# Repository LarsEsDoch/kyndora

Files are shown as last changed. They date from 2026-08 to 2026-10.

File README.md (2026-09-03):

# Kyndora

**Kyndora** is a connected device system that helps two people stay emotionally close across distance. A physical E-Ink display device sits with one partner ("at home"), while a companion mobile app lets the other partner ("away") share their mood, send messages, draw doodles, and let their return time count down, all visible on the device.

The project consists of a custom ESP32-S3 firmware, a FastAPI backend, an MQTT broker for real-time device communication, and a single Flutter app used by both partners.

---

## Table of Contents

- [Concept](#concept)
- [System Architecture](#system-architecture)
- [Hardware](#hardware)
- [Repository Structure](#repository-structure)
- [Features](#features)
  - [On the Device (E-Ink Display)](#on-the-device-e-ink-display)
  - [Mobile App](#mobile-app)
  - [Backend](#backend)
- [Tech Stack](#tech-stack)
- [Getting Started](#getting-started)
  - [Backend & Infrastructure](#backend--infrastructure)
  - [Firmware](#firmware)
  - [Mobile App](#mobile-app-1)
- [Device Provisioning Flow](#device-provisioning-flow)
- [CI/CD](#cicd)
- [Roadmap](#roadmap)
- [License](#license)

---

## Concept

Kyndora is built for couples, families, or friends who are temporarily apart. One person owns the **device**, a small E-Ink display box that sits on a desk or nightstand and passively shows information about their partner: current mood, a daily message, a hand-drawn doodle, the partner's local weather, and a countdown until they return.

The other person carries only the **app**. From anywhere, they can:

- Set their current mood and sleep status
- Send a message or draw a doodle for the day
- Set (or update) their return date/time
- Send an instant "Miss You" ping that lights up the LEDs on the partner's device
- Share their live location and timezone so the device always shows the correct weather and time

Both roles share the same app, the app simply adapts depending on whether a device is registered to the account or not.

## System Architecture

```
┌──────────────────┐        MQTT (WSS)        ┌───────────────────┐
│   ESP32-S3       │◄────────────────────────►│  Mosquitto Broker │
│   Kyndora Device │                          │  (mosquitto-go-   │
│  (E-Ink + LEDs)  │        HTTPS (REST)      │   auth backend)   │
└────────┬─────────┘◄─────────────────────────┴───────────┬───────┘
         │                                                │
         │                                        HTTP auth/ACL
         │                                                │
         ▼                                                ▼
┌─────────────────────────────────────────────────────────────────┐
│                        FastAPI Backend                          │
│  Auth (JWT) · Devices · Partners · Feed · Push · WebSocket      │
│  Weather worker · Timezone resolver · MQTT worker               │
└───────────┬────────────────────────────────────────┬────────────┘
            │                                        │
            ▼                                        ▼
     ┌─────────────┐                          ┌──────────────────┐
     │ PostgreSQL  │                          │  Flutter Mobile  │
     │  (SQLModel) │                          │  App (Android /  │
     └─────────────┘                          │  iOS PWA)        │
                                              └──────────────────┘
```

- The **device** communicates exclusively over MQTT for low-latency, device-only events (commands, status, telemetry) and falls back to plain HTTPS requests for content that doesn't fit an MQTT payload well (e.g. fetching the latest feed item).
- The **app** communicates with the backend over HTTPS for all actions and keeps a **WebSocket** connection open for real-time, user-facing events (partner requests, status changes, new feed items).
- **Push notifications** (Firebase Cloud Messaging for Android, Web Push/VAPID for the iOS PWA) ensure the app owner is notified even when the app isn't open.

## Hardware

| Component | Purpose |
|---|---|
| ESP32-S3 (DevKitC-1-N16R8) | Main microcontroller, WiFi + BLE |
| Waveshare 4.2" E-Paper Display | Primary display (GxEPD2, black/white, partial + full refresh) |
| SK6812 (WS2812B-compatible) LED strip | Ambient/indirect lighting, animations |
| BH1750 digital light sensor | Adaptive LED brightness based on ambient light |
| 4× physical buttons | Miss You, Power/Reset, Next, Previous |
| USB-C panel-mount connector | Power |

Pin mapping and full hardware notes live alongside the firmware source.

## Repository Structure

```
kyndora/
├── firmware/           # ESP32-S3 firmware (PlatformIO, C++/Arduino)
│   ├── include/         # Headers, fonts, icon assets
│   └── src/              # Managers: Display, MQTT, Light, Button, Update, Provisioning
├── backend/            # FastAPI backend (Python)
│   ├── routers/          # auth, device, partners, feed, mqtt, push, users, ws
│   ├── services/         # MQTT worker, weather worker, push, timezone
│   └── tests/            # pytest test suite
├── mobile_app/         # Flutter app (Android + iOS PWA)
│   └── lib/
│       ├── screens/      # Auth, provisioning, device detail, main layout
│       ├── tabs/          # Feed, Devices, Partner
│       └── services/     # Realtime (WebSocket), push, location
├── infrastructure/     # docker-compose, Mosquitto config
├── tools/              # Icon conversion pipeline (PNG → PROGMEM header)
└── .github/workflows/  # CI/CD for backend, firmware, and app
```

## Features

### On the Device (E-Ink Display)

The display is divided into fixed rows, each independently partial-refreshed to minimize flicker and E-Ink wear, with a full refresh every 20 partial updates and once per day:

- **Top bar**, freshness timestamp of the last message + WiFi signal / status icon
- **Time**, large, centered, NTP-synced and timezone-aware
- **Weather**, partner's current local weather icon + temperature (auto-selected icon based on weather code, day/night, and wind)
- **Daily message**, the partner's message for the day
- **Doodle**, the partner's hand-drawn daily doodle, rendered from an 80×80px 1-bit bitmap
- **Countdown**, live countdown until the partner's set return date/time
- **Location**, a short location label with a "stale" indicator if location data hasn't updated recently

Device-side logic includes:

- **LED lighting** with ambient-light-adaptive brightness (BH1750) and a "Miss You" sweep animation
- **Physical buttons** for sending an instant Miss You ping, plus day navigation
- **OTA firmware updates** over GitHub Releases, with support for a `stable` channel and a rolling `beta` channel
- **BLE provisioning** for zero-friction WiFi + account setup, entirely driven from the app
- **NVS-backed persistence** so return time, applied firmware version, timezone, and WiFi credentials survive reboots

### Mobile App

A single Flutter codebase serves both roles:

- **Feed tab**, view messages and doodles sent between partners
- **Devices tab**, list, add (via BLE provisioning), and configure owned devices; per-device settings for display elements, LED brightness/adaptive brightness/night mode, auto-update schedule, and device actions (restart, WiFi reset, cache clear, factory reset)
- **Partner tab**, add a partner by username, send/accept/decline partner requests, send messages, draw and send doodles, set return time, configure timezone (auto-detect via GPS or manual), log mood/sleep status, manage a rotating list of morning quotes, and send an instant "Miss You"
- **Real-time updates** via WebSocket with automatic exponential-backoff reconnection
- **Push notifications**, FCM on Android, Web Push (VAPID) on the installable iOS PWA
- **Background location updates** to keep the partner's weather and timezone accurate

### Backend

- **Auth**, Argon2 password hashing, JWT bearer tokens
- **Partner system**, request/accept/decline flow with real-time and push notifications
- **Device management**, provisioning tickets, per-device settings, telemetry, remote commands
- **MQTT integration**, a background worker consumes device status/heartbeat/telemetry/button events and updates the database; outbound commands are published to device-specific topics (`kyndora/<deviceId>/<topic>`)
- **Weather worker**, polls Open-Meteo every 15 minutes for each user's partner location and pushes updates to the device via MQTT
- **Timezone resolution**, automatic IANA timezone lookup from GPS coordinates, converted to POSIX TZ strings and pushed to the device
- **WebSocket hub**, per-user connection manager for real-time app events
- **Push service**, unified interface over Firebase Admin SDK (FCM) and `pywebpush` (Web Push)
- **Firmware proxy**, exposes a stable `/api/firmware/check` endpoint that resolves the latest GitHub Release asset per channel

## Tech Stack

**Firmware**
ESP32-S3 · PlatformIO · Arduino framework · GxEPD2 · ArduinoJson · PsychicMqttClient (WSS) · FastLED · BH1750 · Preferences (NVS) · BLE

**Backend**
Python · FastAPI · SQLModel · PostgreSQL · JWT (PyJWT) · Argon2 · Eclipse Mosquitto (mosquitto-go-auth, SSL) · firebase-admin · pywebpush · timezonefinder · Open-Meteo API

**Mobile**
Flutter/Dart · Firebase Cloud Messaging · Web Push/VAPID · flutter_blue_plus · geolocator · web_socket_channel

**Infrastructure**
Docker Compose · GitHub Actions (CI/CD) · GitHub Releases (OTA distribution) · GitHub Pages (iOS PWA hosting)

## Getting Started

### Backend & Infrastructure

```bash
cd infrastructure
docker compose up -d          # starts PostgreSQL and the Mosquitto broker
```

```bash
cd backend
python -m venv .venv && source .venv/bin/activate
pip install -r requirements.txt
cp .env.example .env          # configure DB_USER, DB_PASSWORD, JWT_SECRET, MQTT_PASSWORD, etc.
uvicorn main:app --reload
```

Run the test suite:

```bash
pytest
```

### Firmware

```bash
cd firmware
pio run                        # build
pio run -t upload              # flash to an ESP32-S3
```

The build expects an `FW_VERSION` environment variable (set automatically in CI); locally it falls back to `dev-local`.

### Mobile App

```bash
cd mobile_app
flutter pub get
flutter run                    # or: flutter build apk / flutter build web
```

## Device Provisioning Flow

1. The app requests a short-lived provisioning ticket from the backend (`POST /api/device/ticket`), scoped to the logged-in user.
2. The app connects to the device over BLE (advertised as `Kyndora-Setup`) and writes the WiFi SSID, WiFi password, and the provisioning ticket to dedicated GATT characteristics.
3. The device connects to WiFi and calls `POST /api/device/register` with its MAC address and the ticket.
4. The backend validates the ticket, creates (or reassigns) the device record, and returns a permanent device JWT plus MQTT credentials.
5. The device persists these credentials in NVS flash and connects to the MQTT broker over WSS from then on.

## CI/CD

Each part of the monorepo has its own GitHub Actions workflow, triggered on changes to its respective path:

- **`backend.yml`**, lint (ruff), test (pytest), build & push a Docker image to GHCR
- **`firmware.yml`**, build via PlatformIO, publish binaries to a rolling `beta` GitHub Release and to tagged releases
- **`app.yml`**, analyze, test, build Android APK and Flutter Web, deploy the iOS PWA to GitHub Pages, and publish artifacts to GitHub Releases

## Roadmap

- [ ] Tamagotchi-style mood/sleep visualization on the device display
- [ ] Certificate-pinned OTA downloads (replacing `setInsecure()`)
- [ ] LED behavior polish (night mode transitions, do-not-disturb mode)
- [ ] Device-side history browsing (past doodles, moods, locations)
- [ ] Special-event theming for the display

## License

This project is licensed under the GNU General Public License v3.0 - see the [LICENSE](LICENSE) file for details.

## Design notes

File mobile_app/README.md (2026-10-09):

# Kyndora

The official Kyndora App

## Getting Started

This project is a starting point for a Flutter application.

A few resources to get you started if this is your first Flutter project:

- [Learn Flutter](https://docs.flutter.dev/get-started/learn-flutter)
- [Write your first Flutter app](https://docs.flutter.dev/get-started/codelab)
- [Flutter learning resources](https://docs.flutter.dev/reference/learning-resources)

For help getting started with Flutter development, view the
[online documentation](https://docs.flutter.dev/), which offers tutorials,
samples, guidance on mobile development, and a full API reference.

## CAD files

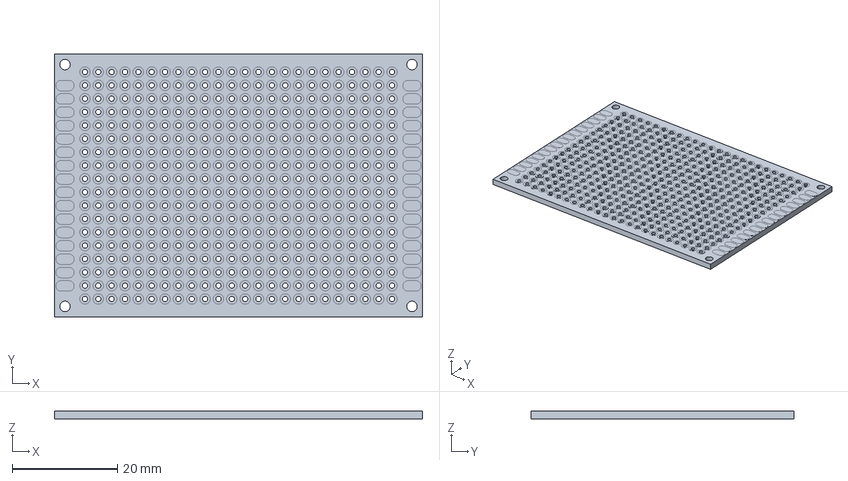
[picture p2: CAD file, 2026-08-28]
docs/cad/models/Perfboard 7x5.stp
70.0 x 50.0 x 1.55 mm

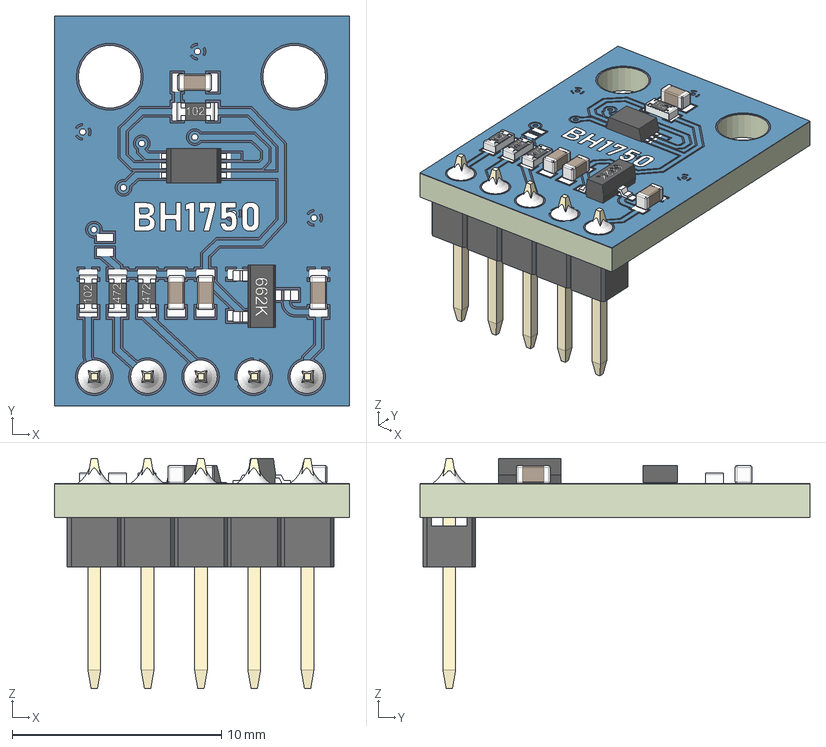
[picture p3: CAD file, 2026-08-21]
docs/cad/models/BH1750.step
14.1 x 18.6 x 11.0 mm
PCB
Font
Stift
Klammer
Solderpoints
662K
Capacitor
Resistor
Resistor (1) x 2
Capacitor (1)
Light-LED

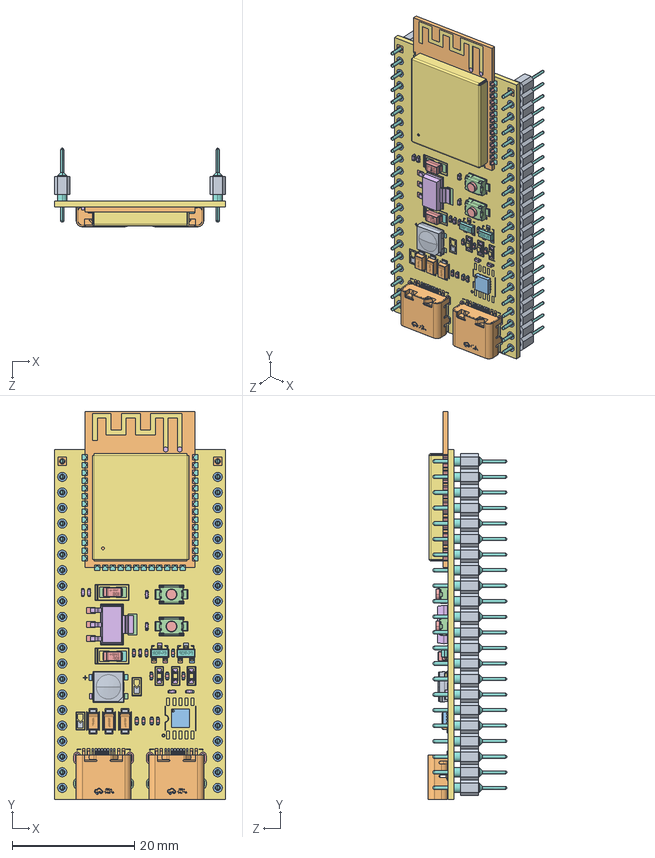
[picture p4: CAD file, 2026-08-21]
docs/cad/models/ESP32-S3-WROOM-1.STEP
27.9 x 63.4 x 12.9 mm
ESP32-S3-WROOM-1
Штыревой разъем 22 конт шаг 2.54мм x 2
USB-C_SMD-TYPE-C-31-M-12~USB-C_SMD-TYPE-C-31-M-12~QTmk.step.STEP x 2
2025-08-30-17-43-03-310.step.STEP x 2
WS2812B
SOT-223
SOT23-3 x 2
SOD-123F x 3
QFN-16 (3x3) Part1.stp
QFN-16 (3x3) Part2.stp x 16
ctantal_case-a_l3-2_w1-6_h1-6 x 2
Body.step x 3
Cover.step x 3
Cover_Mini.step x 3
Insides.step x 3
RC0402 x 10
0402_CA_CB_CC_CD x 7

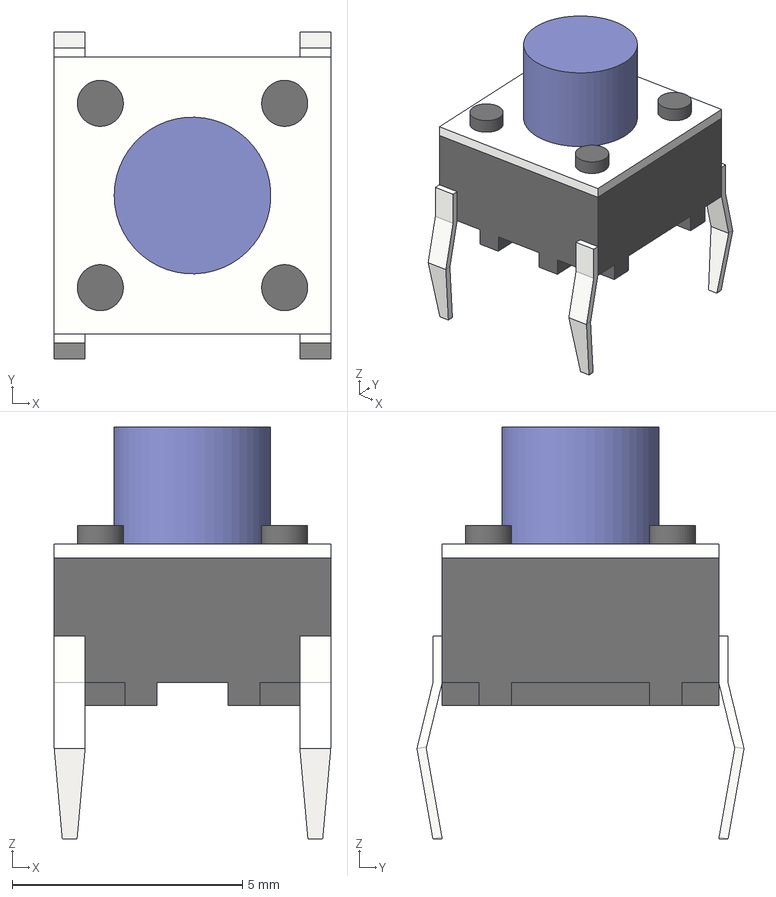
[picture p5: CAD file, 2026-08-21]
docs/cad/models/Micro Momentary Tactile Tact Touch Push Button Switch, 6x6x6 mm.step
6.00 x 7.10 x 8.94 mm

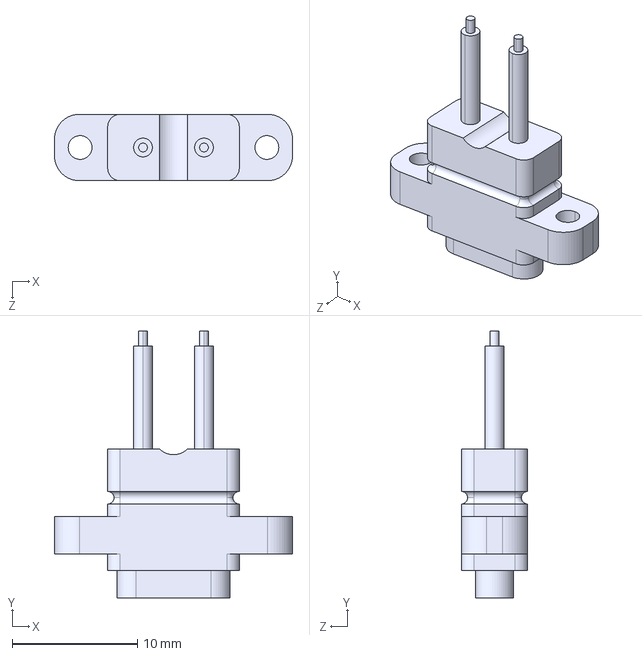
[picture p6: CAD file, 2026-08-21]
docs/cad/models/usb-c.STEP
19.0 x 21.3 x 5.30 mm

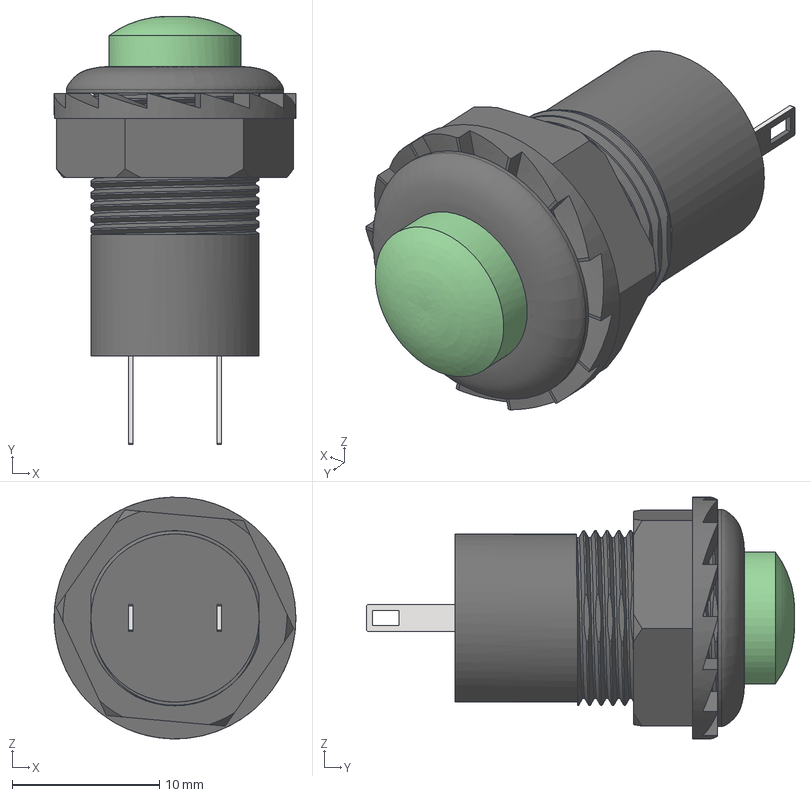
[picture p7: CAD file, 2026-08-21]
docs/cad/models/Momentary Push Button.step
16.4 x 29.0 x 16.4 mm

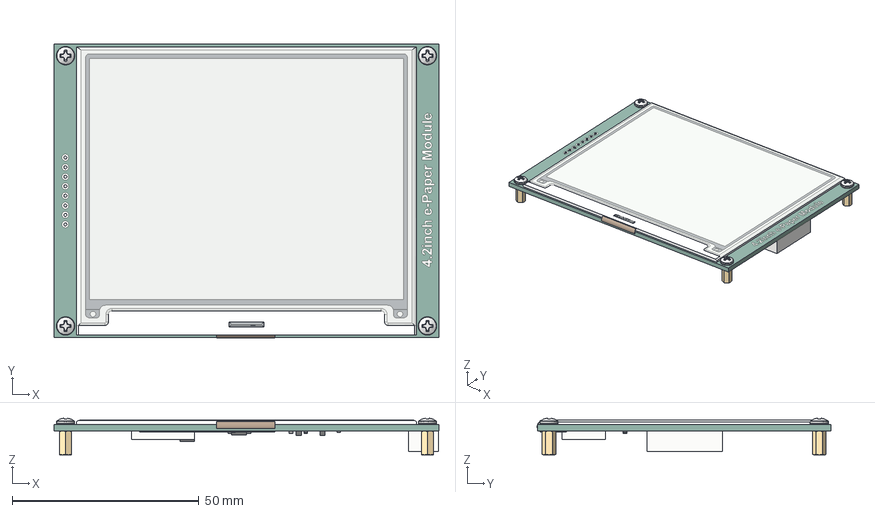
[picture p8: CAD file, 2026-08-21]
docs/cad/models/Waveshare 4.2inch e-Paper Module.step
103.0 x 78.6 x 9.79 mm
Waveshare 4.2 E-Ink - Display folded cable
PCB
90268A201 x 4
91772A030 x 4

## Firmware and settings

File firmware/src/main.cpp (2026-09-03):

#include <Arduino.h>
#include <SPI.h>
#include <WiFi.h>
#include <ctime>
#include "update.hpp"
#include "provisioning.hpp"
#include "mqtt_manager.h"
#include "light_manager.hpp"
#include "display_manager.h"
#include <ArduinoJson.h>
#include "button_manager.h"

#define PIN_EPD_CS    10
#define PIN_EPD_DC     9
#define PIN_EPD_RST   13
#define PIN_EPD_BUSY  46
#define PIN_EPD_SCK   12
#define PIN_EPD_MOSI  11

#define PIN_BTN_MISS_YOU 6
#define PIN_BTN_POWER    7
#define PIN_BTN_NEXT     5
#define PIN_BTN_PREV     4

auto ntpServer = "pool.ntp.org";
String timeZone  = "CET-1CEST,M3.5.0,M10.5.0/3";

uint32_t lastTimeMinutes = 0;
constexpr uint32_t intervalMinute = 60000;

const String otaChannel = "beta";

#ifndef FW_VERSION_STR
#define FW_VERSION_STR ""
#endif
const String currentVersion = String(FW_VERSION_STR).length() > 0 ? String(FW_VERSION_STR) : "dev-local";

DisplayManager displayManager(PIN_EPD_CS, PIN_EPD_DC, PIN_EPD_RST, PIN_EPD_BUSY);
UpdateManager updater(currentVersion, otaChannel, 3, displayManager);
LightManager lightManager;
MqttManager mqttManager;
ButtonManager buttonManager;

int lastMinute = -1;
int lastFullRefreshDay = -1;

uint32_t lastWifiCheck = 0;
constexpr uint32_t wifiCheckInterval = 5000;

bool ntpConfigured = false;
bool ntpSynced = false;
bool mqttStarted = false;
String savedMqttUser = "";
String savedMqttPass = "";
time_t savedReturnTime = 0;

uint32_t wifiDisconnectedSince = 0;
uint32_t lastWifiReconnectAttempt = 0;
constexpr uint32_t wifiReconnectInterval = 10000;
constexpr uint32_t WIFI_RESTART_TIMEOUT_MS = 10UL * 60UL * 1000UL;

constexpr uint32_t POWER_RESET_HOLD_MS = 5000;
bool powerHeld = false;
uint32_t powerHoldStart = 0;

bool getApiErrorFlag() {
    return mqttManager.hasApiError() || updater.hasUpdateError();
}

WifiIconState getCurrentWifiIconState() {
    if (!ProvisioningManager::isProvisioned()) return WIFI_ICON_NOT_SETUP;
    if (!ProvisioningManager::isWiFiConnected()) return WIFI_ICON_NOT_CONNECTED;
    if (getApiErrorFlag()) return WIFI_ICON_ALERT;

    int32_t rssi = WiFi.RSSI();
    if (rssi >= -60) return WIFI_ICON_STRENGTH_4;
    if (rssi >= -70) return WIFI_ICON_STRENGTH_3;
    if (rssi >= -80) return WIFI_ICON_STRENGTH_2;
    return WIFI_ICON_STRENGTH_1;
}

void handlePowerButtonReset() {
    bool pressed = digitalRead(PIN_BTN_POWER) == LOW;

    if (pressed) {
        if (!powerHeld) {
            powerHeld = true;
            powerHoldStart = millis();
        } else if (millis() - powerHoldStart >= POWER_RESET_HOLD_MS) {
            Serial.println("Power button 5s gehalten: Reset wird ausgeloest.");
            ProvisioningManager::reset();
        }
    } else {
        powerHeld = false;
    }
}

void setup() {
    Serial.begin(115200);

    updater.begin();

    SPI.begin(PIN_EPD_SCK, -1, PIN_EPD_MOSI, PIN_EPD_CS);
    displayManager.begin();
    lightManager.begin();
    buttonManager.begin(PIN_BTN_MISS_YOU, PIN_BTN_POWER, PIN_BTN_NEXT, PIN_BTN_PREV);

    ProvisioningManager::begin();

    if (ProvisioningManager::isProvisioned()) {
        Preferences preferences;
        preferences.begin("kyndora", true);
        timeZone = preferences.getString("timezone", "CET-1CEST,M3.5.0,M10.5.0/3");
        savedMqttUser = preferences.getString("mqtt_user", "");
        savedMqttPass = preferences.getString("mqtt_pass", "");
        savedReturnTime = (time_t)preferences.getULong64("return_time", 0);
        Serial.printf("Loaded return time of %llu\n", (unsigned long long) savedReturnTime);
        preferences.end();

        displayManager.setWifiState(getCurrentWifiIconState());
    } else {
        displayManager.showSetupScreen();
    }
}

void loop() {
    uint32_t now = millis();

    ProvisioningManager::handle();
    buttonManager.handle();
    handlePowerButtonReset();

    lightManager.handle();

    if (now - lastWifiCheck >= wifiCheckInterval) {
        lastWifiCheck = now;
        displayManager.setWifiState(getCurrentWifiIconState());
    }

    if (!ProvisioningManager::isProvisioned()) {
        delay(10);
        return;
    }

    bool wifiConnected = ProvisioningManager::isWiFiConnected();

    if (wifiConnected) {
        wifiDisconnectedSince = 0;
    } else {
        if (wifiDisconnectedSince == 0) {
            wifiDisconnectedSince = now;
        }
        if (now - lastWifiReconnectAttempt >= wifiReconnectInterval) {
            lastWifiReconnectAttempt = now;
            Serial.println("Attempting WiFi reconnect...");
            WiFi.reconnect();
        }
        if (now - wifiDisconnectedSince >= WIFI_RESTART_TIMEOUT_MS) {
            Serial.println("WiFi 10 Minuten nicht erreichbar. Neustart...");
            delay(100);
            ESP.restart();
        }
        delay(10);
        return;
    }

    if (!ntpConfigured) {
        ntpConfigured = true;
        configTzTime(timeZone.c_str(), ntpServer);
        Serial.println("NTP sync requested with TZ: " + timeZone);
    }

    if (!ntpSynced) {
        tm timeInfo{};
        if (getLocalTime(&timeInfo, 0)) {
            ntpSynced = true;
            Serial.println("Time successfully synchronized.");

            displayManager.setTime(timeInfo.tm_hour, timeInfo.tm_min);
            lastMinute = timeInfo.tm_min;
            lastFullRefreshDay = timeInfo.tm_mday;

            if (savedReturnTime > 0) {
                displayManager.setReturnTime(savedReturnTime);
            }

            displayManager.setWifiState(getCurrentWifiIconState());
            displayManager.renderFull();
        } else {
            delay(10);
            return;
        }
    }

    if (!mqttStarted) {
        mqttStarted = true;
        String deviceId = WiFi.macAddress();
        deviceId.replace(":", "");
        mqttManager.begin(deviceId, savedMqttUser, savedMqttPass);
    }

    if (buttonManager.hasMissYouPressed()) {
        mqttManager.publishButtonEvent("miss_you");
    }

    mqttManager.handle();

    if (mqttManager.hasPendingLightCommand()) {
        String lightCommand = mqttManager.consumePendingLightCommand();

        if (lightCommand == "rainbow") {
            lightManager.setRainbowMode();
        } else if (lightCommand == "warm_white") {
            lightManager.setWarmWhiteMode();
        } else if (lightCommand == "miss_you") {
            lightManager.playMissYouAnimation();
        }
    }

    if (mqttManager.hasPendingUpdateCheck()) {
        mqttManager.clearPendingUpdateCheck();
        updater.checkForUpdates();
    }

    if (now - lastTimeMinutes >= intervalMinute) {
        lastTimeMinutes = now;
        updater.automaticCheckForUpdates();
    }

    if (mqttManager.hasNewWeather()) {
        mqttManager.clearNewWeatherFlag();
        displayManager.setWeather(
            mqttManager.getWeatherTemp(),
            mqttManager.getWeatherCode(),
            mqttManager.getWeatherIsDay(),
            mqttManager.getWeatherWindy()
        );
    }

    if (mqttManager.hasNewReturnTime()) {
        mqttManager.clearNewReturnTimeFlag();
        displayManager.setReturnTime(mqttManager.getReturnTime());
    }

    if (mqttManager.hasNewContent()) {
        mqttManager.clearNewContentFlag();

        String responseJson = mqttManager.fetchLatestMessage("api.bogatzhome.com");

        if (responseJson.length() > 0) {
            JsonDocument doc;
            DeserializationError error = deserializeJson(doc, responseJson);

            if (!error && doc["has_new"] == true) {
                String contentType = doc["type"];
                String payload = doc["payload"].as<String>();

                if (contentType == "doodle") {
                    displayManager.setDoodle(payload);
                } else {
                    displayManager.setMessage(payload);
                }
            }
        }
    }

    tm timeInfo{};
    if (!getLocalTime(&timeInfo, 0)) {
        delay(10);
        return;
    }

    if (timeInfo.tm_min != lastMinute) {
        lastMinute = timeInfo.tm_min;
        displayManager.setTime(timeInfo.tm_hour, timeInfo.tm_min);
        displayManager.updateCountdown();
    }

    if (timeInfo.tm_mday != lastFullRefreshDay) {
        lastFullRefreshDay = timeInfo.tm_mday;
        displayManager.renderFull();
    }

    delay(10);
}

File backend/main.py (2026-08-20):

import asyncio
from contextlib import asynccontextmanager

from fastapi import FastAPI
from starlette.middleware.cors import CORSMiddleware

from database import create_db_and_tables
from mqtt_client import connect_mqtt
from routers import auth, device, doodles, feed, mqtt, partners, push, users, ws
from services.mqtt_worker import init_mqtt_worker
from services.weather_worker import init_weather_worker


@asynccontextmanager
async def lifespan(app: FastAPI):
    print("Starting Backend.")
    create_db_and_tables()

    app.state.loop = asyncio.get_running_loop()

    print("Starting MQTT Client.")
    connect_mqtt()
    print("Starting MQTT Worker.")
    init_mqtt_worker()
    print("Starting Weather Worker.")
    init_weather_worker()
    yield


app = FastAPI(title="Kyndora API", lifespan=lifespan)

origins = [
    "http://localhost",
    "http://localhost:8080",
    "http://localhost:51117",
    "https://api.bogatzhome.com",
    "https://larsesdoch.github.io",
]

app.add_middleware(
    CORSMiddleware,
    allow_origins=origins,
    allow_credentials=True,
    allow_methods=["*"],
    allow_headers=["*"],
)

app.include_router(auth.router)
app.include_router(doodles.router)
app.include_router(device.router)
app.include_router(mqtt.router)
app.include_router(partners.router)
app.include_router(feed.router)
app.include_router(users.router)
app.include_router(ws.router)
app.include_router(push.router)


@app.get("/")
def read_root():
    return {
        "status": "online",
        "system": "Kyndora Backend",
        "message": "All systems are running correctly. Go to /docs for the API overview.",
    }

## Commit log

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2026-03-20 Add security utilities: hashing & JWT auth
    Introduce backend/security.py providing authentication helpers for FastAPI: Argon2 password hashing (get_password_hash, verify_password), JWT access token creation (create_access_token) and an OAuth2 dependency (oauth2_scheme) with get_current_user_id to decode and validate tokens. Loads SECRET_KEY from env (with a default fallback), sets HS256 algorithm and a 30-day token expiry, and handles expired/invalid token errors. This centralizes auth logic for user login and protected endpoints.
    [security.py]
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2026-05-20 Switch to GxEPD2 and add WiFi/NTP clock
    Replace GxEPD2_4G dependency with zinggjm/GxEPD2 and update includes to use GxEPD2/GxEPD2_BW. Refactor EPD pin defines and SPI initialization, set up display with a larger font, and remove the old grayscale demo. Add WiFi connection and NTP time synchronization, then update the e-ink display with a partial window to show the current time (updated each second/minute) and perform a full refresh on the hour. Minor cleanup: removed PSRAM/debug prints and adjusted display init parameters.
    [main.cpp]
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2026-05-22 Implement automatic GitHub OTA update check
    Add time-based automaticCheckForUpdates using getLocalTime and lastCheckDay to trigger a single daily check at the configured hour. Implement checkForUpdates to verify WiFi, call the GitHub releases API, and parse the response (tag_name and browser_download_url) to detect newer firmware. On new releases the download URL is stored and executeOTA() is invoked. Also add HTTPS client setup (WiFiClientSecure with setInsecure), HTTP headers, redirect handling, and basic logging/error messages.
    [update.cpp]
2026-05-22 Implement OTA download and flashing in executeOTA
    Add full OTA flow to UpdateManager::executeOTA: create a WiFiClientSecure (setInsecure) and HTTPClient (strict redirects), start download with a custom User-Agent, check HTTP 200 and content length, begin Update with the content size, stream firmware via Update.writeStream, verify bytes written, handle Update.end()/isFinished() and restart on success, and log errors and progress. Keeps downloadUrl cleared on success and includes a TODO for a waiting screen.
    [update.cpp]
2026-05-22 Call updater, translate logs, and rename time vars
    Include update.hpp and invoke updater.automaticCheckForUpdates() in loop to enable automatic update checks. Rename German variables to English (letzteMinute -> lastMinute, letzteNTPUpdate -> lastNTPUpdate) and switch to a tm timeInfo variable. Translate Serial output messages from German to English and fix the time check to compare minutes (tm_min) instead of seconds. Also reduce the delay on failed local time retrieval and tidy related setup/wait messages.
    [main.cpp]
2026-05-22 Refactor UpdateManager: OTA, parsing, checks
    Improve robustness and clarity in firmware update flow. Change WiFi status call, loosen scheduled update check to trigger on or after the configured hour, and add early return if no download URL is available. Use const where appropriate and raw string literals for JSON key searches, simplify HTTP/Update handling (use getStream reference, direct Update.begin check, const sizes) and improve logging. Add a small delay before restart after a successful update to ensure messages are flushed.
    [update.cpp]
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2026-05-22 Use secrets.h and constexpr intervals
    Move WiFi credentials out of main.cpp into a separate secrets.h (added to .gitignore) and include it from main.cpp. Replace hardcoded ssid/password variables with WIFI_SSID and WIFI_PASSWORD, and change interval constants to constexpr for clearer intent and potential compile-time optimization. Minor wiring: print the new WIFI_SSID when connecting.
    [main.cpp]
2026-06-25 Add user auth endpoints and DB integration
    Replace basic FastAPI app with full user auth flow: add registration (/register), login (/login) with OAuth2 form support, a protected /users/me endpoint, and a health root (/) endpoint. Integrates SQLModel Session via get_session, the User model, and security helpers for password hashing, verification, and JWT access token creation. Also updates app title to "Kyndora API" and returns appropriate HTTP status codes and messages on register/login.
    [main.py]
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2026-07-26 Refactor auth endpoints and initialize MQTT
    Move authentication and user management endpoints to separate routers (auth and doodles). Add MQTT client connection to app lifespan for automatic startup. Simplify main.py to focus on app setup and routing. Update MQTT broker IP configuration.
    [main.py]
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2026-07-26 Add provisioning manager and ArduinoJson
    Introduce ProvisioningManager (provisioning.cpp/.hpp) to exchange a ticket for device credentials via HTTP POST and persist device_jwt/mqtt credentials to Preferences (NVS). Add bblanchon/ArduinoJson to platformio.ini and fix lib_deps spacing for GxEPD2. Also remove an unused WiFiClientSecure include from update.hpp. This enables device provisioning flow (hits /api/device/register) and saves credentials for later use.
    [provisioning.cpp]
2026-07-26 Add BLE provisioning manager and integrate main
    Implements a BLE-based provisioning flow and integrates it into main.cpp. Adds ProvisioningManager (firmware/src/provisioning.{hpp,cpp}) to advertise a BLE service, receive SSID/password/token, save credentials & JWT/MQTT data to Preferences, and exchange the ticket with the backend. Replaces direct secrets.h Wi‑Fi logic in main.cpp with ProvisioningManager calls, shows a "Awaiting Setup via Bluetooth" splash when unprovisioned, and conditions NTP/update/display logic on provisioning/Wi‑Fi state. Also tweaks timing/update checks and restarts after successful provisioning.
    [main.cpp, provisioning.cpp]
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2026-07-26 Show success dialog after provisioning completes
    Update provisioning flow UI: change final status to 'Data sent to Kyndora. Finalizing...', increase final delay to 3s, disconnect the device, clear the processing flag and set 'Provisioning successful!'. Display an AlertDialog on success that notifies the user and pops back to the previous screens. Error handling is unchanged.
2026-07-27 Add MQTT auth/ACL endpoints
    Introduce a new MQTT router (backend/routers/mqtt.py) exposing /api/mqtt/auth and /api/mqtt/acl. The auth endpoint decodes a JWT (from the password) using JWT_SECRET and verifies the token 'sub' matches the clientid; the acl endpoint permits access when the clientid is present in the topic. Register the router in backend/main.py. Both endpoints return HTTP 401 on failure.
    [main.py]
2026-07-27 Add MQTT manager for device communication
    Implement MQTT connectivity with a new MqttManager class that handles broker connections, heartbeat publishing, and telemetry transmission. Add PubSubClient dependency and update ArduinoJson to v7.4.3. Initialize MQTT manager in main setup with device credentials from preferences and integrate handle loop for automatic reconnection and heartbeat scheduling.
    [main.cpp, mqtt_manager.cpp]
2026-07-27 Remove debug code and increase WiFi retry limit
    Remove debug print statement from MQTT authentication endpoint to prevent logging sensitive token information. Increase WiFi connection retry attempts from 20 to 30 to allow more time for device connection during provisioning.
    [provisioning.cpp]
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2026-07-27 Tighten MQTT topic authorization logic
    Refactor authorize_mqtt_topic to use a local username variable and tighten authorization checks. Admins are still allowed, but non-admins now must provide a clientid that appears in the topic and the topic must start with "kyndora/". This prevents accidental authorization when "kyndora/" appears anywhere in the topic or when clientid is empty.
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2026-07-27 Add periodic telemetry publishing to MQTT manager
    Add telemetry scheduling and sending to MqttManager. Introduces _lastTelemetry and TELEMETRY_INTERVAL, calls sendTelemetry() on connect and periodically from handle(). Implements sendTelemetry() to build a JSON payload (rssi, ssid, uptime_s, free_heap, core_temp, battery_v, battery_percent), serialize it and publish to kyndora/<device>/telemetry with success/failure logging. Also guards publishing with mqttClient.connected().
    [mqtt_manager.cpp]
2026-07-27 Persist MQTT heartbeat/telemetry to DB
    Enhance backend MQTT worker to handle full topic paths and persist device data to the database. Adds imports for SQLModel, engine, Device and Telemetry, plus a format_mac helper. Subscribes to 'kyndora/+/#', validates topic parts, distinguishes 'heartbeat' and 'telemetry' messages, and updates existing Device/Telemetry records (committing changes and updating last_seen_at for heartbeats). Adds JSON decode handling and a default MQTT_PASSWORD fallback when env var is missing. Intended to store incoming MQTT status/telemetry in Postgres via SQLModel.
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2026-07-28 Add MQTT command endpoint for devices
    Introduce a POST /api/device/{mac_address}/command endpoint that sends commands to devices via MQTT. Adds MQTT_BROKER and MQTT_PORT constants, uses paho.mqtt.publish to publish payloads to topic kyndora/{mac}/commands, and enforces device existence and ownership checks (404/403). MQTT credentials use admin and MQTT_PASSWORD from environment; failures return 500. Note: ensure paho-mqtt is added to project dependencies.
    [mqtt_manager.cpp]
2026-07-28 Defer JSON parsing; support raw status messages
    Decode MQTT payload as a raw string and special-case 'status' topics to store the raw status and update last_seen without attempting json.loads. Postpone json.loads until handling structured messages (heartbeat, telemetry). Reorganizes branches so heartbeat and telemetry use the parsed payload. This prevents JSONDecodeError for non-JSON status payloads while preserving existing telemetry updates.
2026-07-28 Add feed router and MQTT content endpoint
    Register a new feed router and add POST /api/feed to create ContentFeed records and notify the partner's device via MQTT. backend/routers/feed.py was added (uses get_current_user, DB session, and paho.mqtt.publish) and main.py now includes the feed router. Endpoint saves content, selects the partner's Device, and publishes a trigger message to kyndora/<mac>/content using MQTT credentials (MQTT_PASSWORD env var with default). Basic error logging is included when MQTT publish fails.
    [main.py]
2026-07-28 Normalize MACs and add device latest content endpoint
    Add format_mac helper to normalize MAC addresses to upper-case colon-separated form. Use normalized MAC (no colons, upper-case) when composing MQTT topic for partner notifications. Introduce new GET endpoint /device/{mac_address}/latest which retrieves the latest undelivered ContentFeed for the device owner, marks it as displayed, and returns has_new, id, type and payload. Returns has_new: false if nothing found; raises HTTPException (status_code 4404) when device or owner is missing.
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2026-07-28 Add timezone support and POSIX mapping
    Add a timezone field to Device (defaulting to a CET POSIX string) and introduce a utility to map IANA zone names to POSIX TZ strings. Added backend/utils.py with get_posix_tz() that loads backend/zones.json and falls back with a warning if the file is missing. Included backend/zones.json with a comprehensive IANA→POSIX mapping. This enables storing device timezones and converting IANA names to POSIX format where needed.
    [models.py]
2026-07-28 Add endpoint to set partner device timezone
    Introduce POST /api/device/display-timezone to let a user set their partner device's display timezone. Adds imports (json, utils, User, get_current_user), updates router tag to 'Devices', validates partner assignment, converts IANA name to a POSIX TZ via utils.get_posix_tz, persists the change to the DB, and publishes an MQTT 'set_timezone' command to the partner device (uses MQTT_PASSWORD from env). Minor import/order adjustments and basic MQTT error logging included.
2026-07-28 Show online/offline, add DevTools config
    Display device status in the dashboard ListTile (shows 'Connected' when dev['status']=='online', otherwise 'Offline'). Add mobile_app/devtools_options.yaml to store Flutter DevTools settings. Fix widget test import casing in mobile_app/test/widget_test.dart (package:Kyndora/main.dart).
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2026-07-29 Add DeviceDetailScreen for device management
    Add mobile_app/lib/screens/device_detail_screen.dart: a StatefulWidget (token, macAddress, deviceName) that fetches device info from backendUrl via HTTP, displays status and telemetry (RSSI, uptime, free heap, temperature), supports refresh and sends a restart command. Handles loading/error states and uses German UI strings.
2026-07-29 Use device detail screen; update feed endpoint
    Replace expandable device tiles with Card/ListTile that navigates to DeviceDetailScreen (passes token, macAddress, deviceName) and refreshes list on return. Remove inline restart command and related helper from devices tab. Change feed API call from /api/feed/history to /api/feed. Clean up a few stray comments in auth_screen, main_layout and partner_tab. These changes move device actions into a dedicated detail screen and simplify list UI.
2026-07-29 Add device details endpoint and user feed
    models.py: set Device.name default to mac_address. backend/routers/device.py: add GET /{mac_address} to return device metadata and latest telemetry (formats last_seen, exposes temperature), and fix authorization check in send_device_command to compare user IDs correctly. backend/routers/feed.py: import or_ and add GET / feed endpoint to return the 5 most recent ContentFeed items for the current user with direction (sent/received) and formatted timestamps.
    [models.py]
2026-07-29 Add JSON parsing and doodle rendering
    Introduce JSON message handling and support for 'doodle' image payloads.
    - firmware/src/main.cpp: include ArduinoJson; add drawDoodle(String) which validates a 1600-char hex string, decodes it to an 800-byte buffer and draws an 80x80 bitmap centered on the e-paper display. Update loop to deserialize JSON responses (has_new/type/payload). If type == "doodle" the payload is rendered via drawDoodle, otherwise payload is shown as partner text.
    - firmware/src/mqtt_manager.cpp: fetchLatestMessage now returns the raw JSON response string (instead of extracting payload), and log messages/error text updated.
    [main.cpp, mqtt_manager.cpp]
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2026-07-31 Refactor icons and add WiFi icon rendering
    Replace weather_icons include and fix icon identifiers; rename slash-containing symbols to valid constants (e.g. ICON_CLEAR_DAY, ICON_CLOUD, ICON_WIFI_ALERT, etc.).
    Refactor drawIconBitmap to accept a target size and scale by sampling the source bitmap so icons can be drawn at different sizes. Introduce WEATHER_ICON_TARGET_SIZE and WIFI_ICON_TARGET_SIZE, and adjust weather layout to use display.width() and position text relative to the icon.
    Add WiFi status support: WifiIconState enum, getApiErrorFlag, getCurrentWifiIconState, wifiIconBitmap and drawWifiIcon. The main loop now periodically checks WiFi state and redraws the WiFi icon only when it c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
    [main.cpp]
2026-07-31 Add error flags and accessors for MQTT and OTA
    Track and expose API/OTA error state: MqttManager gains _apiError and hasApiError(), and sets the flag based on HTTP fetch success/failure. UpdateManager gains updateError and hasUpdateError(), and sets/clears the flag for missing Wi‑Fi, successful API responses, and HTTP/API failures. Also minor cleanup in OTA flashing flow. Files changed: firmware/include/mqtt_manager.h, firmware/src/mqtt_manager.cpp, firmware/src/update.cpp, firmware/src/update.hpp.
    [mqtt_manager.cpp, update.cpp]
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2026-08-03 Update server test IP addresses to new server
    Update MQTT broker and database IP addresses across backend services and firmware from 192.168.178.33 to 192.168.178.32. Changes applied to database connection, MQTT client initialization in routers and workers, and firmware configuration.
    [main.cpp]
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2026-08-07 Use zero display init and stop printing MQTT payloads
    Set display init baud/flags to 0 in DisplayManager and remove printing of full MQTT message payloads for heartbeat and telemetry to Serial. This reduces serial clutter and avoids exposing message contents in logs. Modified files: firmware/src/display_manager.cpp, firmware/src/mqtt_manager.cpp.
    [mqtt_manager.cpp]
2026-08-08 Replace device detail screen with settings UI
    Refactors DeviceDetailScreen to present a device settings UI instead of the previous status/telemetry view. Adds many state fields (display elements, LED config, night mode, firmware/update settings, network info, etc.), ExpansionTiles with SwitchListTile/Sliders, and interactive actions. Replaces network calls with placeholder fetch/sync/command stubs (including a small artificial delay). Removes the old _deviceDetails-based cards and restartDevice logic, introducing _syncSetting and _executeCommand placeholders to POST updated settings/commands to the backend.
2026-08-08 Render doodles in feed and improve UI
    Enhance the feed tab to render 'doodle' content inline and improve overall feed UI. Replaces the simple ListTile with a Card containing an icon/label and either a text payload or a drawn doodle. Adds DoodleDisplayPainter to render a monochrome 80x80 grid from a hex-encoded bitmap (expects hex length = (gridSize*gridSize)/4). Also: switch feed-empty text to English, replace a debug print with throwing an Exception, and add a brief FETCH comment near the HTTP request.
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2026-08-12 Fix Flutter analyzer issues
    This patch removes unused imports and converts static demo values in the device detail and partner tabs to final fields to satisfy Flutter analyzer warnings. It also makes the CI analyze step non-blocking so the workflow continues even when static analysis reports existing issues.
2026-08-13 Update widget test to target AuthScreen
    Replace the default counter widget test with an AuthScreen UI smoke test. Import screens/auth_screen.dart instead of main.dart, instantiate AuthScreen inside a MaterialApp, call pumpAndSettle, and assert the presence of a 'Password' label and at least one ElevatedButton. Removes legacy counter-related expectations.
2026-08-17 Add firmware check API router
    Add backend/routers/firmware.py: a FastAPI APIRouter mounted at /api/firmware with GET /check. It queries the GitHub Releases API for LarsEsDoch/kyndora (supports stable, beta, or explicit version tag), finds an asset ending with 'firmware.bin', and returns channel, version, download_url, and updated_at. Includes error handling for invalid channels, missing releases/assets, and GitHub API errors. Uses httpx.AsyncClient for async requests.
2026-08-18 Add timezone service and dependency
    Introduce backend/services/timezone_service.py to detect IANA timezones via timezonefinder, convert to POSIX TZ, persist to user/device and push timezone to partner devices over MQTT. Add timezonefinder to backend/requirements.txt. Tidy imports and error formatting in backend/routers/device.py and minor newline/format fixes in firmware and tests. Also expose get_current_user in device router imports for downstream use.
2026-08-18 Centralize timezone resolution and push
    Move timezone resolution and partner-device push into services.timezone_service (resolve_and_push_partner_timezone). Update /api/partners and /api/users routers to call the service and return resolved_timezone. Add validation in partners.set_timezone to require iana_timezone when auto_detect is disabled. Small cleanup: reorder imports, adjust model imports, tighten typing in timezone service (str | None), and improve MQTT exception string formatting.
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2026-08-19 Add MQTT factory reset command
    This change adds a new MQTT command, `factory_reset`, which clears all persisted Kyndora settings via Preferences and restarts the device after a 3 second delay. It enables remote factory reset workflows from the MQTT broker.
    [mqtt_manager.cpp]
2026-08-19 Fix device name default and user ID typing
    Avoid referencing mac_address at class definition by setting Device.name default to an empty string instead of Field(default=mac_address). Also change generate_provisioning_ticket's current_user_id dependency from str to UUID and remove the redundant UUID(...) conversion when creating ProvisioningTicket. These changes prevent a NameError and fix a type mismatch when creating provisioning tickets.
    [models.py]
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2026-08-20 Update app deployment and sync settings
    Allow requests from GitHub Pages in the backend CORS configuration, reduce the periodic location background sync interval to 1 minute for faster updates, and rename the PWA short name to improve how the app appears on installed web apps.
    [main.py]
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2026-08-22 Improve LightManager: power cap, rainbow, settings
    Add LED power cap (FastLED.setMaxPowerInVoltsAndMilliamps(5,1000)), correct brightness mapping, and replace static white with a moving rainbow animation. Update hardware/config: NUM_LEDS -> 14, DATA_PIN -> 21, and reduce checkInterval from 250ms to 10ms. Also remove noisy Serial output. These changes limit current draw, fix lux->brightness scaling, and enable a smoother multi-LED visual effect.
    [light_manager.hpp]
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2026-08-27 Restrict BLE provisioning discovery
    The firmware now advertises its provisioning service with the standard BLE preferred intervals, and the mobile app filters scanning to the Kyndora setup service UUID. This reduces discovery noise and improves pairing reliability during provisioning.
    [provisioning.cpp]
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2026-08-29 Switch to PsychicMqttClient (WSS) and add buttons
    Replace PubSubClient with PsychicMqttClient and migrate MQTT to secure WebSocket (MQTT_SERVER_URI). Add embedded CA cert, client credentials, will, topics and event-based callbacks (onConnect/onDisconnect/onTopic/onError). Refactor mqtt_manager API (removed broker IP arg, added isConnected(), internal topic strings, simplified handle/publish logic, improved heartbeat/telemetry publishing, and JSON command/content handlers). Also add four hardware button pins (power/back/forward/miss_you) with pull-ups and a debug print for the MISS_YOU button.
    [main.cpp, mqtt_manager.cpp]
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2026-08-29 Add unstable build to OTA function
    [main.cpp, update.cpp]
2026-09-03 Pass new version to OTA; improve update logging
    Add more informative logging (print update channel and include apiUrl on HTTP errors), refactor version comparison, and change executeOTA to accept the newVersion. executeOTA now saves the applied version after a successful OTA. Update the header prototype accordingly. Files changed: firmware/src/update.cpp, firmware/src/update.hpp.
    [update.cpp]
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2026-09-03 Async Wi‑Fi, deferred NTP/MQTT & power reset
    Make Wi‑Fi non‑blocking and resilient: add Wi‑Fi event handler and async connect flow in ProvisioningManager (with connect timeout, reconnect attempts and 10min restart fallback). Defer NTP configuration and wait for NTP sync before starting MQTT; persist and use saved MQTT credentials/return time. Add Wi‑Fi icon logic to use ProvisioningManager::isWiFiConnected, lightweight power‑button 5s reset handler, and various flags/intervals for reconnects and startup sequencing. Minor safety tweaks to Wi‑Fi disconnect and BLE provisioning flow.
    [main.cpp, provisioning.cpp]
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2026-10-06 Allow long-lived device auth and MQTT fallback
    Device registration now issues a 10-year JWT so device clients keep working across refresh intervals. MQTT auth now tolerates expired JWTs when the token is a device token and still validates the client ID against the MAC address, while the token helper accepts custom expiry durations.
    [security.py]
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
